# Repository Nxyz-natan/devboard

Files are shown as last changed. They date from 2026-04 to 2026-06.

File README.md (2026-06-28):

# devboard
A compact ESP32 development board with onboard 2" ST7789 display, USB-C, LiPo charging via IP5306, GPIO headers, status LEDs, and CH340C for easy programming. Built on the ESP32-WROOM-32 for WiFi and Bluetooth.
Screenshot 2026-04-13 at 12 08 58 AM
my finished pcb
Screenshot 2026-04-13 at 3 15 34 PM

my finished schematics

## Bill of Materials

| Name | Purpose | Qty | Total Cost (USD) | Distributor | Link |
|---|---|-----|---|---|---|
| PCB | PCB | 1 | $1.50 | JLCPCB | - |
| Mini Hotplate | Soldering | 1 | $13.26 | Amazon | - |
| LiPo Battery 1000mAh JST | Battery | 1 | $7.83 | Amazon | - |
| LCSC ST7789 2.0inch Screen | Screen | 1 | $7.67 | LCSC | [link](https://www.lcsc.com/product-detail/C53184555.html) |
| ESP32-WROOM-32-N4 | MCU | 1 | $4.29 | LCSC | [link](https://www.lcsc.com/product-detail/C82899.html) |
| K2-1102SP Push Button | Button | 10 | $0.45 | LCSC | [link](https://www.lcsc.com/product-detail/C127509.html) |
| YLED0402Y LED Yellow | LED | 50 | $0.69 | LCSC | [link](https://www.lcsc.com/product-detail/C20608782.html) |
| EVERLIGHT Green LED | LED | 10 | $0.43 | LCSC | [link](https://www.lcsc.com/product-detail/C74338.html) |
| NATIONSTAR Red LED | LED | 50 | $0.67 | LCSC | [link](https://www.lcsc.com/product-detail/C84256.html) |
| YAGEO 100R 0402 | Resistor | 100 | $0.09 | LCSC | [link](https://www.lcsc.com/product-detail/C106232.html) |
| UNI-ROYAL 1K 0402 | Resistor | 100 | $0.07 | LCSC | [link](https://www.lcsc.com/product-detail/C11702.html) |
| YAGEO 10K 0603 | Resistor | 100 | $0.15 | LCSC | [link](https://www.lcsc.com/product-detail/C98220.html) |
| YAGEO 5.1K 0402 | Resistor | 100 | $0.09 | LCSC | [link](https://www.lcsc.com/product-detail/C105872.html) |
| Samsung 100uF 1206 Cap | Capacitor | 10 | $0.61 | LCSC | [link](https://www.lcsc.com/product-detail/C15008.html) |
| YAGEO 100nF 0402 Cap | Capacitor | 100 | $0.10 | LCSC | [link](https://www.lcsc.com/product-detail/C60474.html) |
| Samsung 10uF 0603 Cap | Capacitor | 50 | $0.40 | LCSC | [link](https://www.lcsc.com/product-detail/C19702.html) |
| Pin Header 1x20 2.54mm | Header | 50 | $0.72 | LCSC | [link](https://www.lcsc.com/product-detail/C50981.html) |
| Pin Header 1x2 2.54mm | Header | 10 | $0.61 | LCSC | [link](https://www.lcsc.com/product-detail/C49661.html) |
| USB-C Receptacle 14P | Connector | 5 | $0.85 | LCSC | [link](https://www.lcsc.com/product-detail/C165948.html) |
| MMBT3904 NPN Transistor | Transistor | 50 | $0.49 | LCSC | [link](https://www.lcsc.com/product-detail/C20526.html) |
| 2N7002 MOSFET | MOSFET | 50 | $0.67 | LCSC | [link](https://www.lcsc.com/product-detail/C8545.html) |
| IP5306 Battery IC | Power | 5 | $1.41 | LCSC | [link](https://www.lcsc.com/product-detail/C181692.html) |
| AMS1117-3.3 LDO | Regulator | 5 | $1.13 | LCSC | [link](https://www.lcsc.com/product-detail/C6186.html) |
| CH340C USB-UART | USB-UART | 1 | $0.58 | LCSC | [link](https://www.lcsc.com/product-detail/C84681.html) |
| JST B2B-PH-K-S(LF)(SN) | JST PH 2.0mm 2pin vertical connector | 20 | $0.67 | LCSC | [link](https://www.lcsc.com/product-detail/C131337.html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) |
soldering paste  soldering   5.09$
soldering tweeters	placing down components	-	$5.89	-	aliexpress

total with shipping and tax: $74.93 usd

finished soldering
lo-2

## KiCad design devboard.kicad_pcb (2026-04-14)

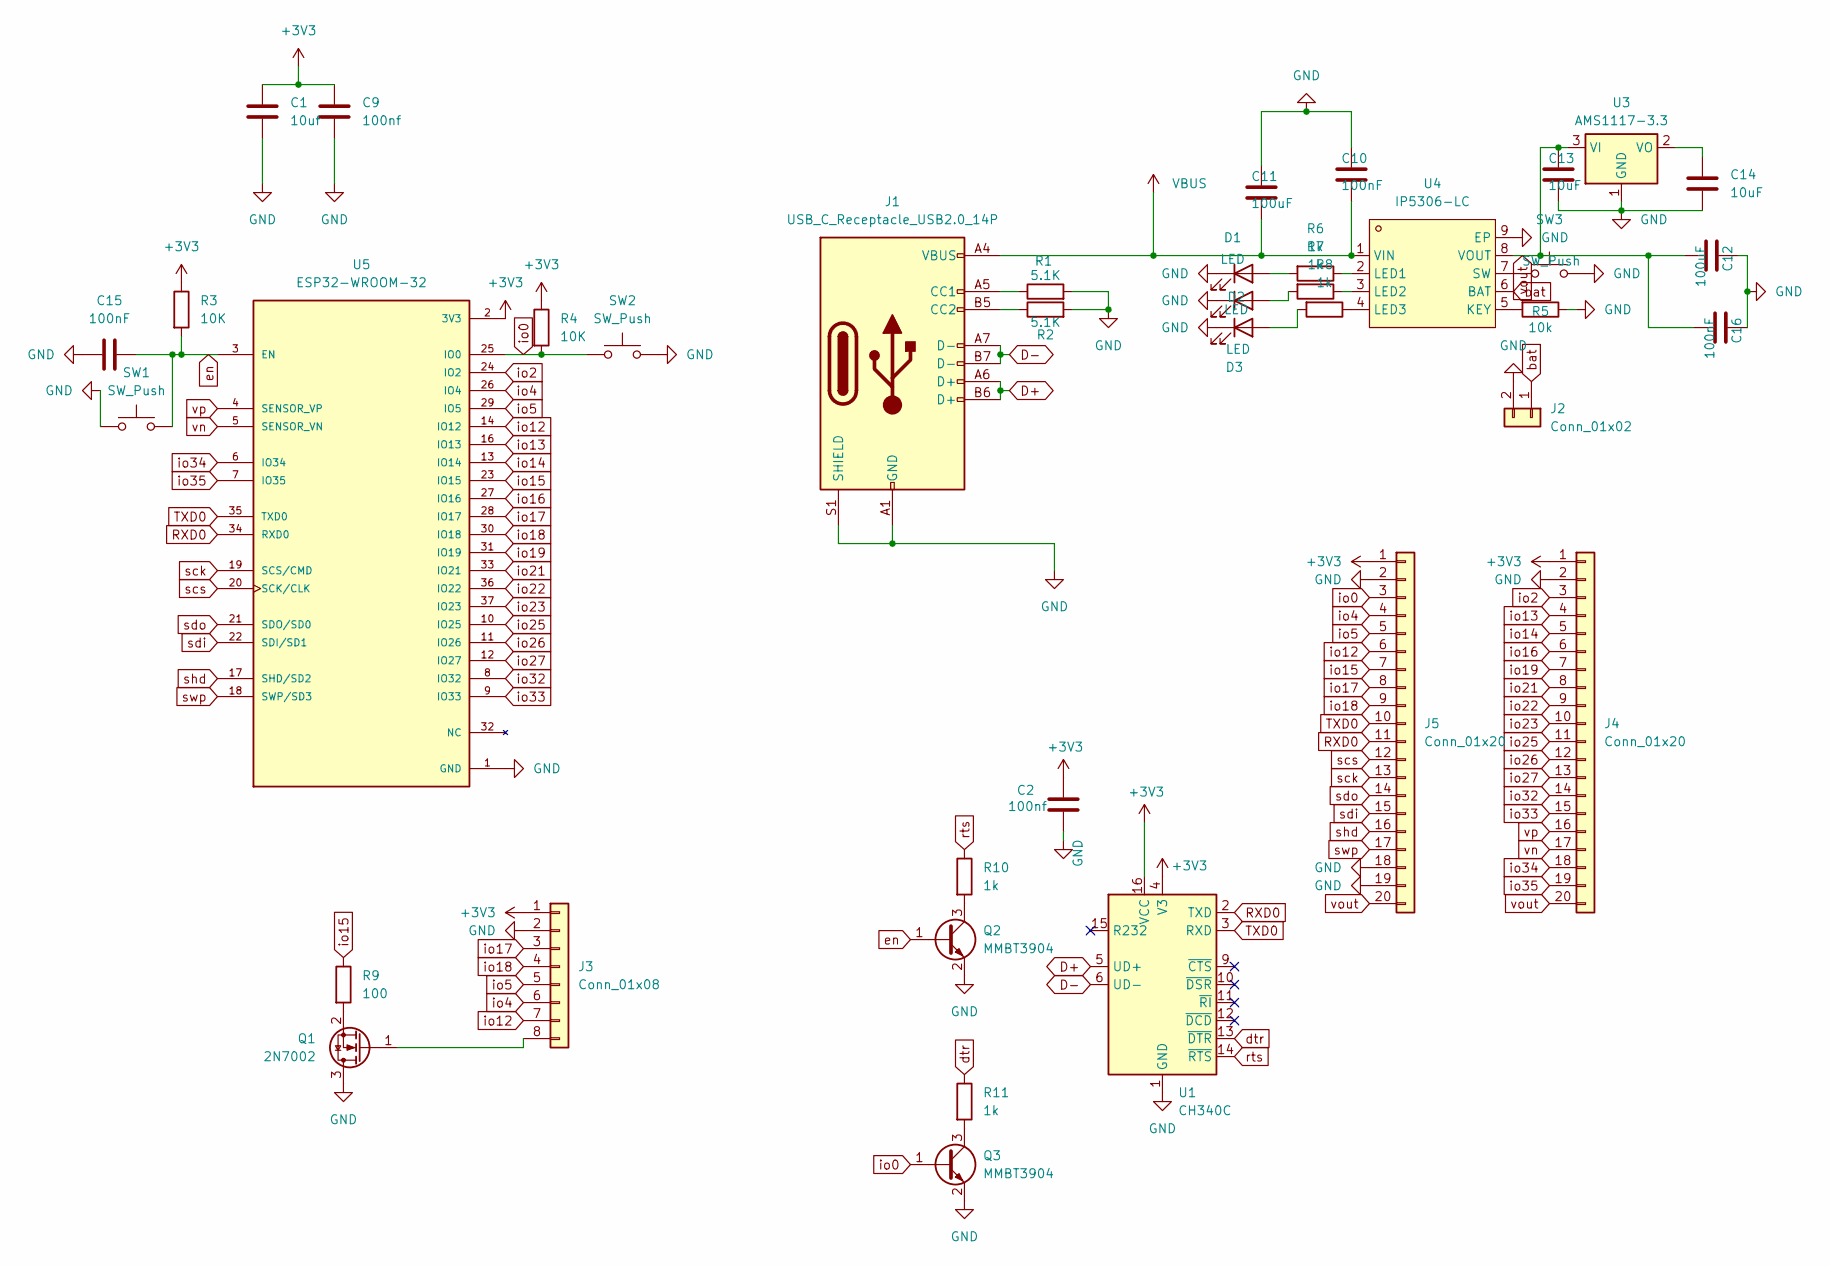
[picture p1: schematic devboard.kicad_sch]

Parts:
C1: 10uf; C_0603_1608Metric
C2, C9: 100nf; C_0402_1005Metric
C10, C16: 100nF; C_0603_1608Metric
C11, C12: 100uF; C_1206_3216Metric
C13, C14: 10uF; C_0603_1608Metric
C15: 100nF; C_0402_1005Metric
D1, D2, D3: LED; LED_0402_1005Metric
J1: USB_C_Receptacle_USB2.0_14P; USB_C_Receptacle_HRO_TYPE-C-31-M-12
J2: Conn_01x02; JST_PH_S2B-PH-K_1x02_P2.00mm_Horizontal
J3: Conn_01x08; PinHeader_1x08_P2.54mm_Vertical
J4, J5: Conn_01x20; PinHeader_1x20_P2.54mm_Vertical
Q1: 2N7002; SOT-23
Q2, Q3: MMBT3904; SOT-23
R1, R2: 5.1K; R_0402_1005Metric
R3, R4: 10K; R_0402_1005Metric
R5: 10k; R_0402_1005Metric
R6, R7, R8, R10, R11: 1k; R_0402_1005Metric
R9: 100; R_0402_1005Metric
SW1, SW2, SW3: SW_Push; SW_SPST_TL3342
U1: CH340C; SOIC-16_3.9x9.9mm_P1.27mm
U3: AMS1117-3.3; SOT-223-3_TabPin2
U4: IP5306-LC; ESOP-8_L4.9-W3.9-P1.27-LS6.0-BL-EP; MPN IP5306-LC; LCSC Part C605440
U5: ESP32-WROOM-32; MODULE_ESP32-WROOM-32; PARTREV 2.9

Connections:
+3V3: C1.1, C2.1, C9.1, J3.1, J4.1, J5.1, R3.1, R4.1, U1.4 (V3), U1.16 (VCC), U5.2 (3V3)
D+: J1.A6 (D+), J1.B6 (D+), U1.5 (UD+)
D-: J1.A7 (D-), J1.B7 (D-), U1.6 (UD-)
GND: C1.2, C2.2, C9.2, C10.1, C11.1, C12.1, C13.2, C14.2, C15.1, C16.1, D1.1 (K), D2.1 (K), D3.1 (K), J1.A1 (GND), J1.A12 (GND), J1.B1 (GND), J1.B12 (GND), J1.S1 (SHIELD), J2.2, J3.2, J4.2, J5.2, J5.18, J5.19, Q1.3 (D), Q2.2 (E), Q3.2 (E), R1.2, R2.2, R5.1, SW1.1, SW2.2, SW3.2, U1.1 (GND), U3.1 (GND), U4.9 (EP), U5.1 (GND), U5.15 (GND), U5.38 (GND), U5.39_1 (GND), U5.39_2 (GND), U5.39_3 (GND), U5.39_4 (GND), U5.39_5 (GND), U5.39_6 (GND), U5.39_7 (GND), U5.39_8 (GND), U5.39_9 (GND), U5.39_10 (GND), U5.39_11 (GND), U5.39_12 (GND), U5.39_13 (GND), U5.39_14 (GND), U5.39_15 (GND), U5.39_16 (GND), U5.39_17 (GND), U5.39_18 (GND), U5.39_19 (GND), U5.39_20 (GND), U5.39_21 (GND)
unnamed: D1.2 (A), R6.2
unnamed: D2.2 (A), R7.2
unnamed: D3.2 (A), R8.2
unnamed: J1.A5 (CC1), R1.1
unnamed: J1.B5 (CC2), R2.1
unnamed: J3.8, Q1.1 (G)
unnamed: Q1.2 (S), R9.2
unnamed: Q2.3 (C), R10.2
unnamed: Q3.3 (C), R11.2
unnamed: C14.1, U3.2 (VO)
unnamed: R5.2, U4.5 (KEY)
unnamed: R6.1, U4.2 (LED1)
unnamed: R7.1, U4.3 (LED2)
unnamed: R8.1, U4.4 (LED3)
unnamed: SW3.1, U4.7 (SW)
RXD0: J5.11, U1.2 (TXD), U5.34 (RXD0)
TXD0: J5.10, U1.3 (RXD), U5.35 (TXD0)
VBUS: C10.2, C11.2, J1.A4 (VBUS), J1.A9 (VBUS), J1.B4 (VBUS), J1.B9 (VBUS), U4.1 (VIN)
bat: J2.1, U4.6 (BAT)
dtr: R11.1, U1.13 (~DTR)
en: C15.2, Q2.1 (B), R3.2, SW1.2, U5.3 (EN)
io0: J5.3, Q3.1 (B), R4.2, SW2.1, U5.25 (IO0)
io2: J4.3, U5.24 (IO2)
io4: J3.6, J5.4, U5.26 (IO4)
io5: J3.5, J5.5, U5.29 (IO5)
io12: J3.7, J5.6, U5.14 (IO12)
io13: J4.4, U5.16 (IO13)
io14: J4.5, U5.13 (IO14)
io15: J5.7, R9.1, U5.23 (IO15)
io16: J4.6, U5.27 (IO16)
io17: J3.3, J5.8, U5.28 (IO17)
io18: J3.4, J5.9, U5.30 (IO18)
io19: J4.7, U5.31 (IO19)
io21: J4.8, U5.33 (IO21)
io22: J4.9, U5.36 (IO22)
io23: J4.10, U5.37 (IO23)
io25: J4.11, U5.10 (IO25)
io26: J4.12, U5.11 (IO26)
io27: J4.13, U5.12 (IO27)
io32: J4.14, U5.8 (IO32)
io33: J4.15, U5.9 (IO33)
io34: J4.18, U5.6 (IO34)
io35: J4.19, U5.7 (IO35)
rts: R10.1, U1.14 (~RTS)
sck: J5.13, U5.19 (SCS/CMD)
scs: J5.12, U5.20 (SCK/CLK)
sdi: J5.15, U5.22 (SDI/SD1)
sdo: J5.14, U5.21 (SDO/SD0)
shd: J5.16, U5.17 (SHD/SD2)
swp: J5.17, U5.18 (SWP/SD3)
vn: J4.17, U5.5 (SENSOR_VN)
vout: C12.2, C13.1, C16.2, J4.20, J5.20, U3.3 (VI), U4.8 (VOUT)
vp: J4.16, U5.4 (SENSOR_VP)

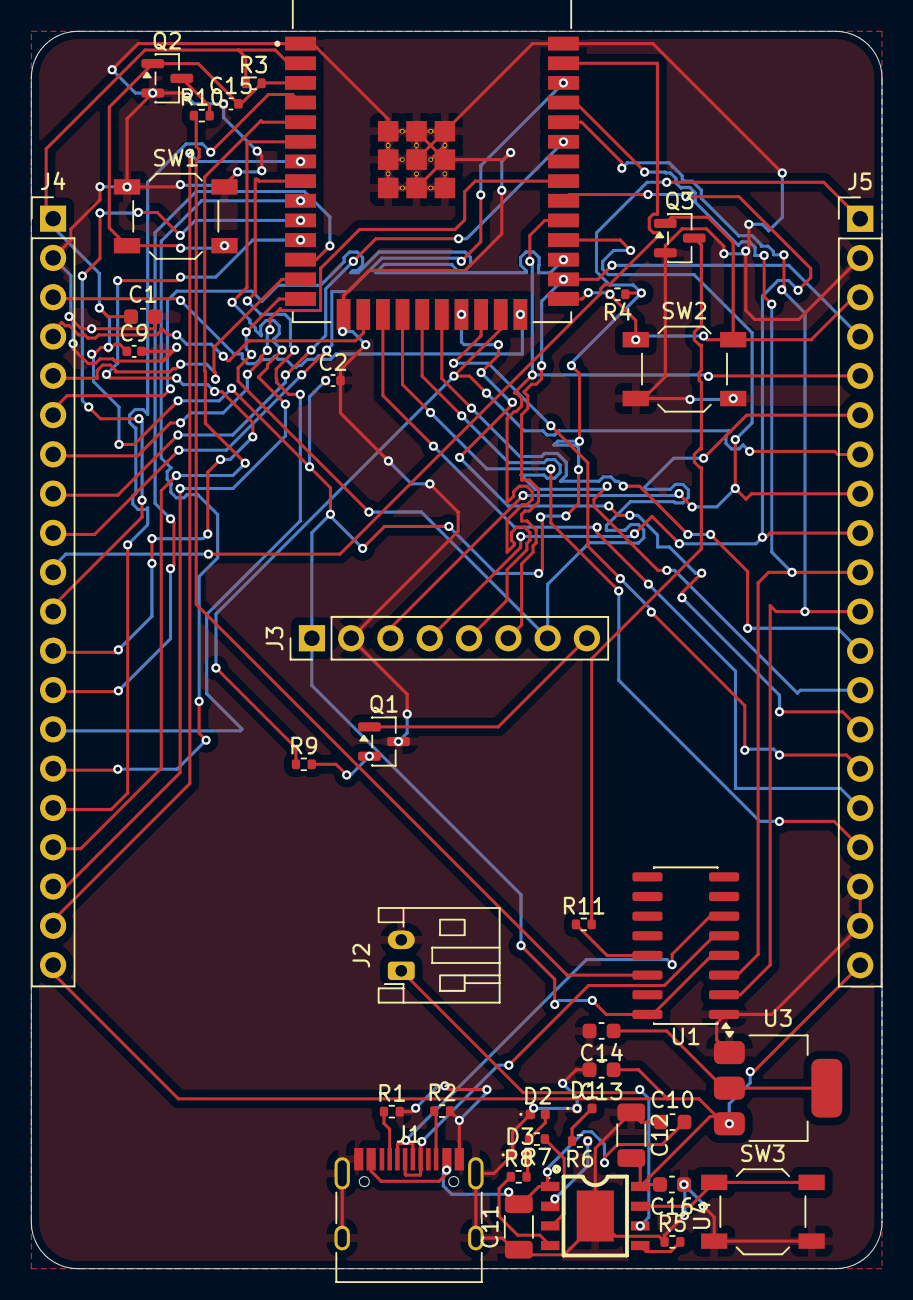
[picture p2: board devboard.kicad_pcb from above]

Board: 2 copper layers, 55.0 x 80.0 mm, 39 parts (0 on the bottom side), 57 nets.

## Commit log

2026-04-13 Create pcb
2026-06-28 Add image of finished soldering project
    Added an image of the finished soldering project.
